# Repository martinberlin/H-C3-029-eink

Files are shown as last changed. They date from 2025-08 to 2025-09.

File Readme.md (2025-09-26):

### nRF52840 mini Badger PCB

This PCB design is based on [this nRF52 module datasheet](https://jlcpcb.com/api/file/downloadByFileSystemAccessId/8612736116701077504)

> E73 - 2 G4 M0 8 S1C are wireless Bluetooth modules designed by
Chengdu Ebyte which feature small size, low power consumption. It
adopt the originally imported RFIC nRF52840 of NORDIC, supporting BLE 4. 2 and BLE 5. 0 . The chip has high- performance ARM CORTEX- M4 F kernel and other peripheral resources, such as
UART, I2C, SPI, ADC, DMA, PWM etc.

The most important goals that this PCB achieves:

 - Very low power consumption. In factors of 2 digits micro-amperes (uA) per minute
 - Simple user interface with a multi-directional switch (up, down, select)
 - All open source, including the BLE sending program (MacOS /iOS)
 - Very simple design and schematics
 - QWIIC connector so can support external I2C sensors (Consumption limit: 200mA, limited by LDO MCP1700-330) 

### PCB 3D Render

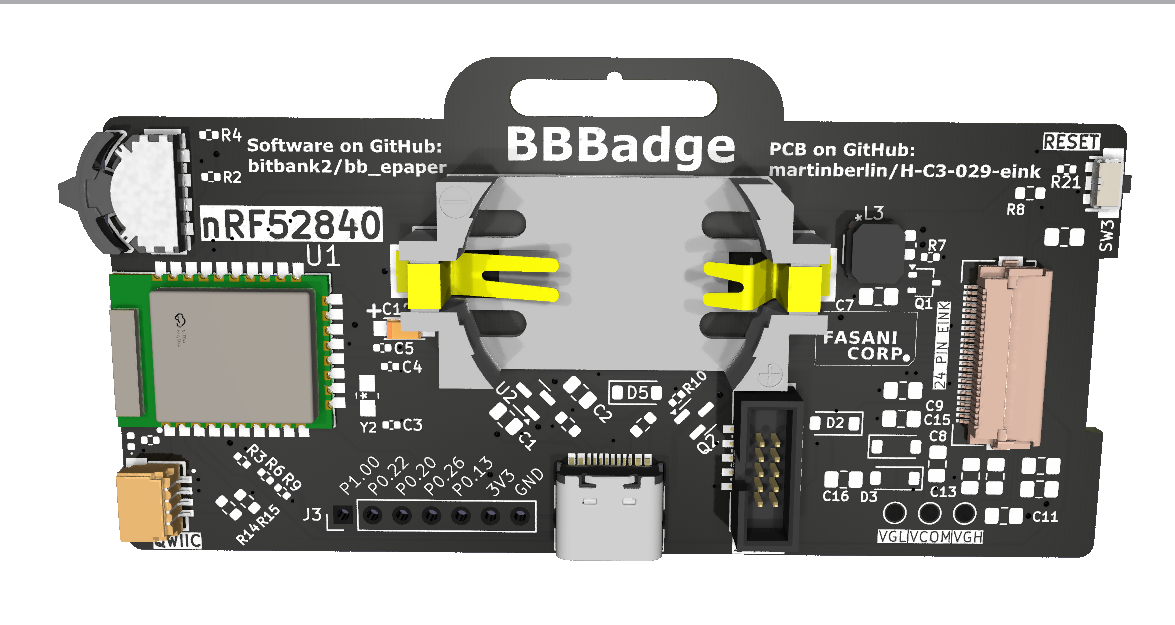
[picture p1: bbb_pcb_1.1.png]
PCB Render


### Related repositories

[MFR Badge](https://github.com/bitbank2/MFRBadge) MacOS/iOS app to program the Maker Faire Rome badges

[bb_epaper](https://github.com/bitbank2/bb_epaper) Larry Bank library for SPI epaper displays

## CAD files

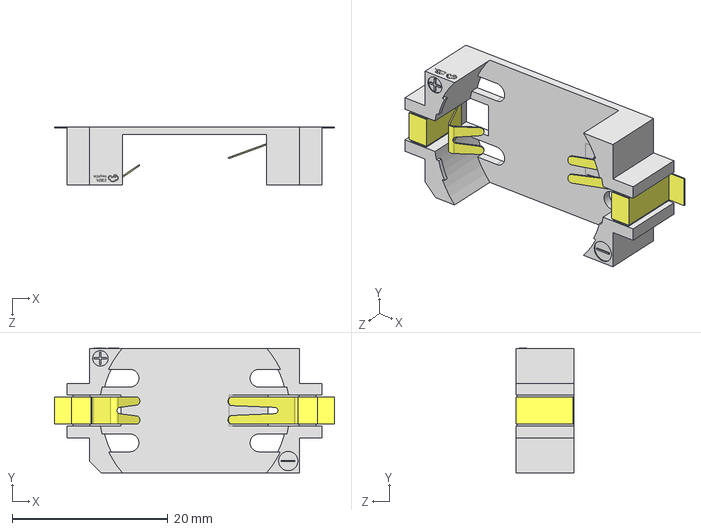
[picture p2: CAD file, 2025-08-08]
H-C3-2.9/components/3D/BAT-SMD_BS-24-B4AA016.step
36.0 x 16.0 x 7.51 mm

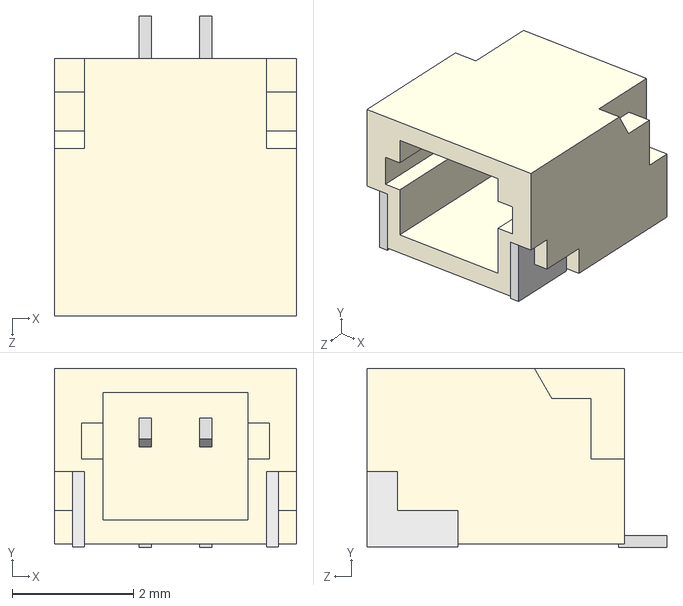
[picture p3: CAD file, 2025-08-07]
H-C3-2.9/components/3D/JST_SM02B-SRSS-TB__LF__SN.stp
4.00 x 2.96 x 4.95 mm

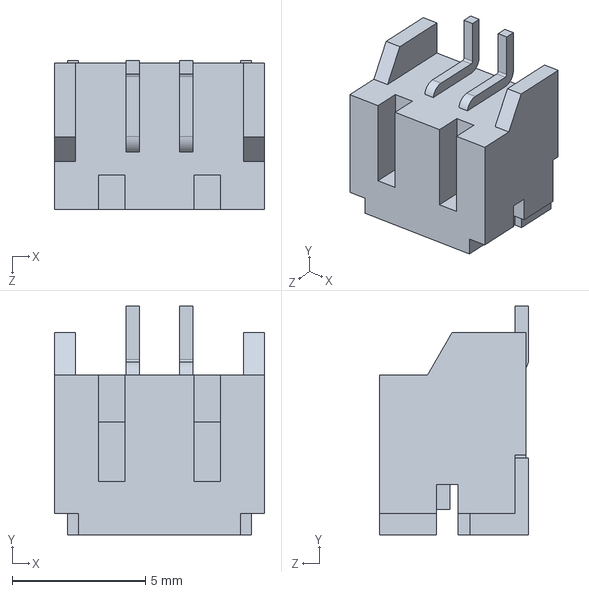
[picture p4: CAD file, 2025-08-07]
H-C3-2.9/components/3D/S2B-PH-SM4-TB_LF__SN_.stp
7.90 x 8.60 x 5.60 mm

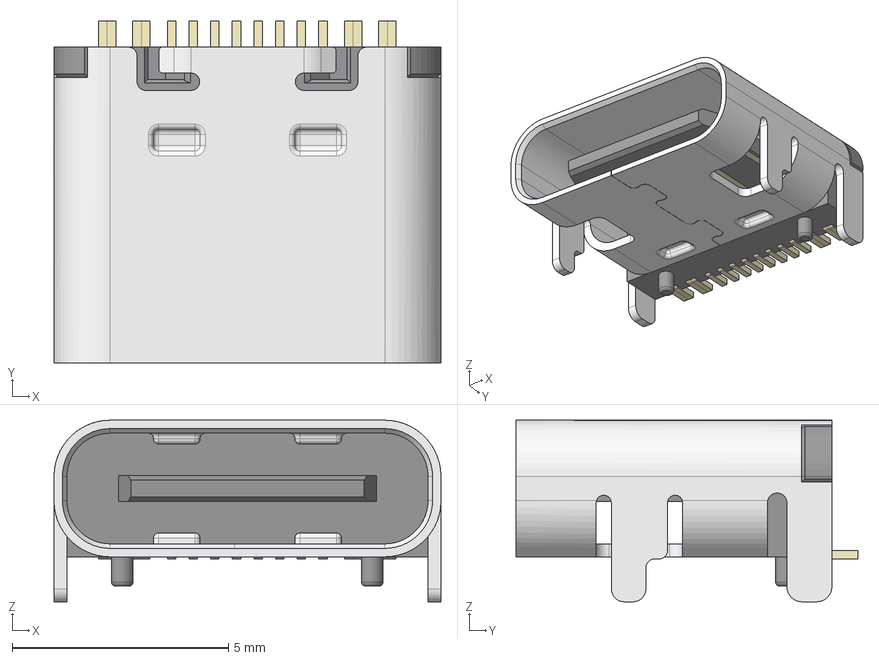
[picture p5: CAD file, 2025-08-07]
H-C3-2.9/components/3D/USB_TYPE-C-31-M-12.step
8.95 x 7.90 x 4.20 mm

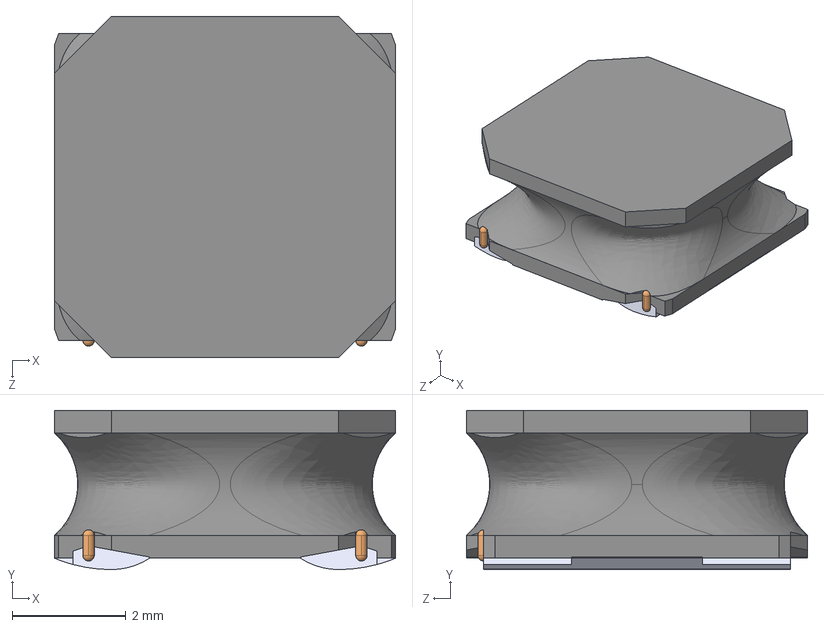
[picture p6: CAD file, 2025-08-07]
H-C3-2.9/components/3D/L-40xx.stp
6.00 x 2.80 x 6.00 mm

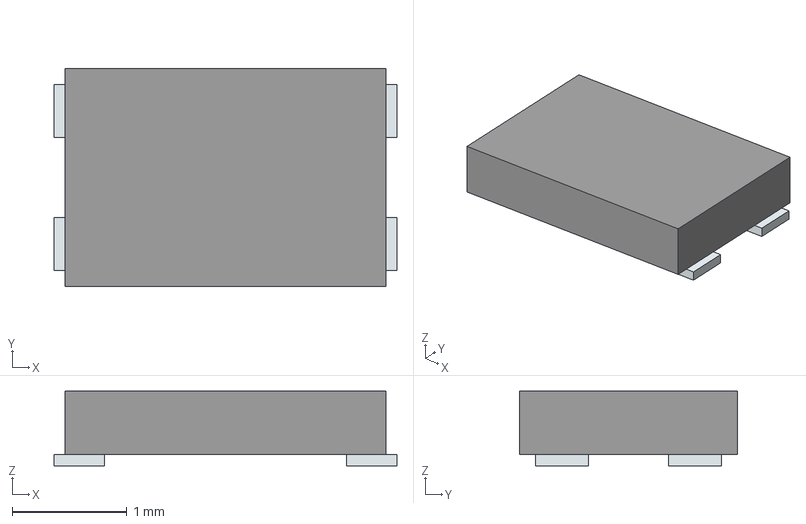
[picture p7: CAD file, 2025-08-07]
H-C3-2.9/components/3D/switch_SKSVCCE010.stp
2.99 x 1.90 x 0.65 mm
Pins

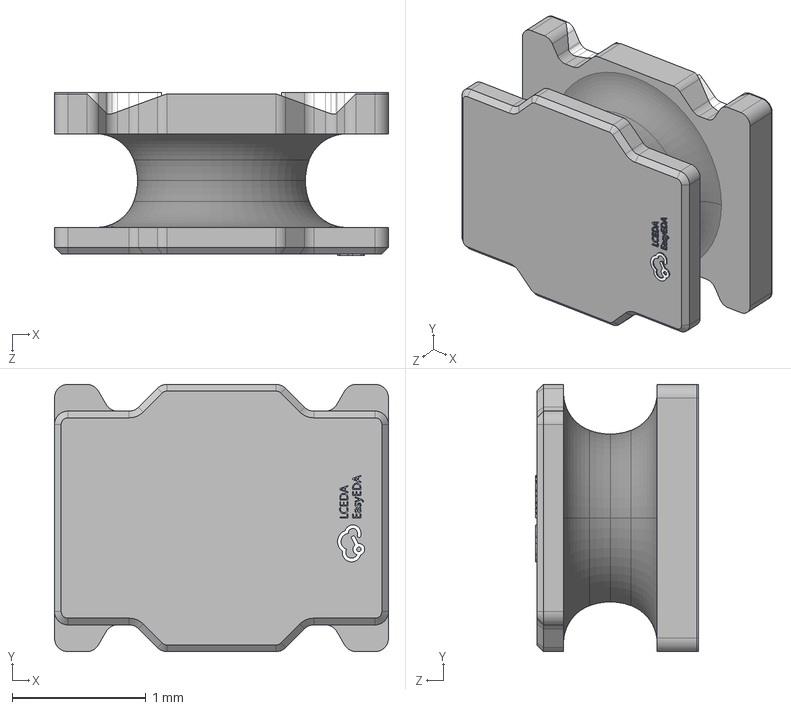
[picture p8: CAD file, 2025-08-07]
H-C3-2.9/components/3D/IND-SMD_L2.5-W2.0-H1.2_SPH252012.step
2.50 x 2.00 x 1.22 mm

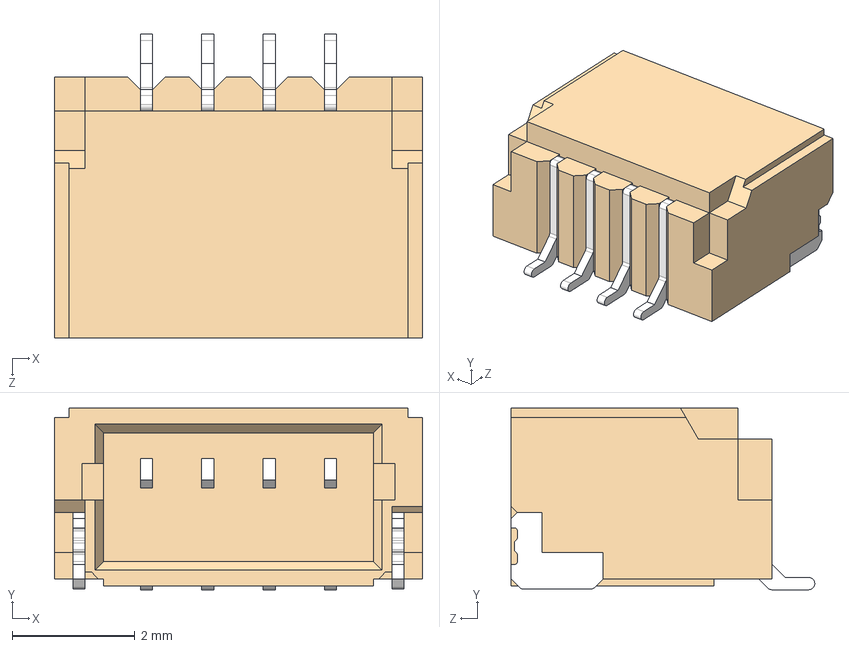
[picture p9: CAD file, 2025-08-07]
H-C3-2.9/components/3D/QWIIC_SM04B-SRSS-TB_LF__SN_.stp
6.00 x 2.96 x 4.95 mm

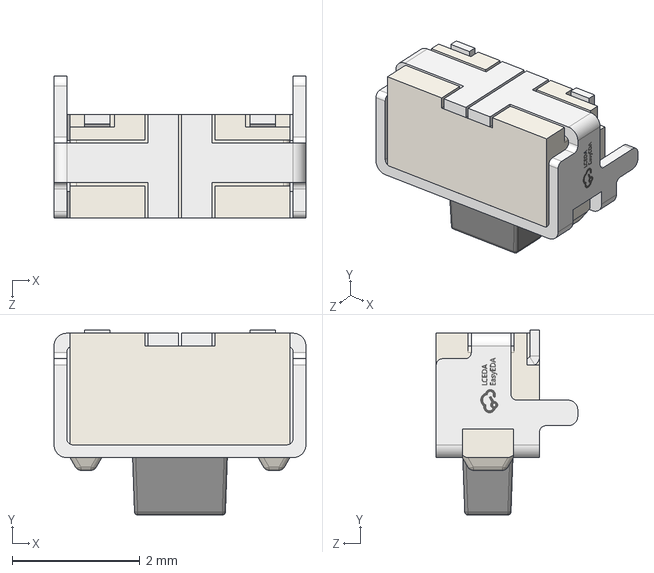
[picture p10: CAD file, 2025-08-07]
H-C3-2.9/components/3D/KEY-SMD_L4.0-W2.9-H1.6-P3.75.step
3.95 x 2.90 x 2.22 mm

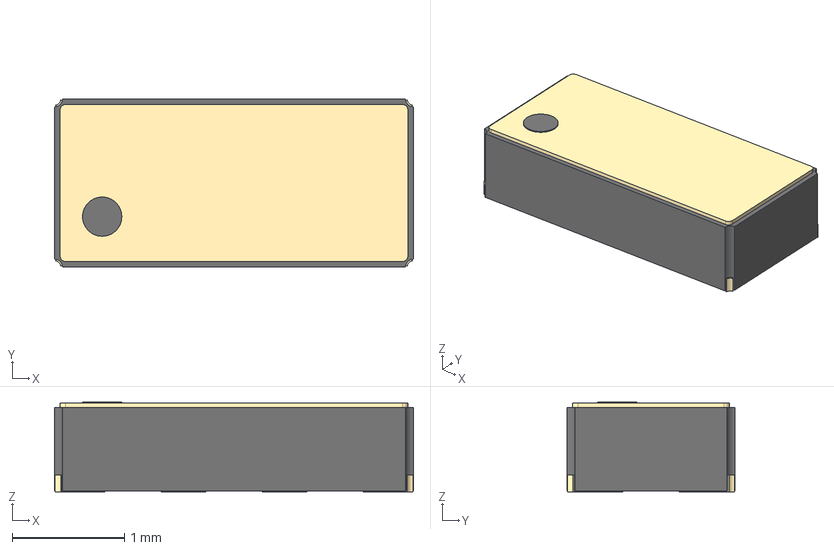
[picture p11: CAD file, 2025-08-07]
H-C3-2.9/components/3D/RV-3032-C7.stp
3.20 x 1.50 x 0.8 mm
Rect2
Rect3
Rect4
Rect5
Terminal

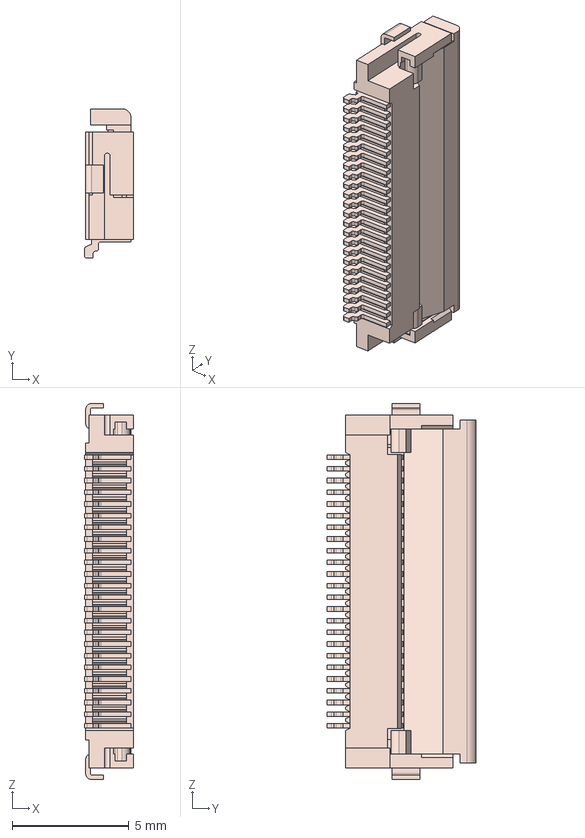
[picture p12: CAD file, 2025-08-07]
H-C3-2.9/components/3D/FH12-24S-0.5SH_55_.step
2.10 x 6.40 x 16.1 mm

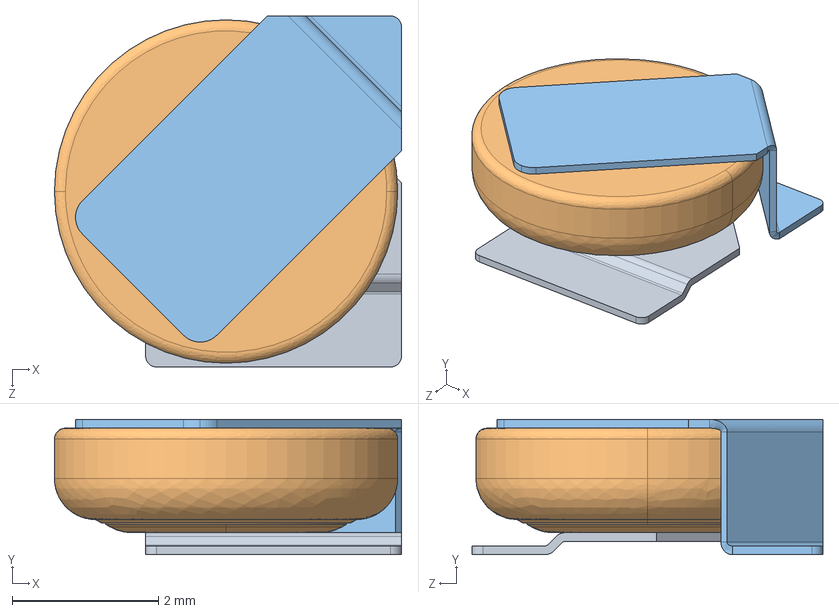
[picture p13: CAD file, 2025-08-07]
H-C3-2.9/components/3D/SuperCAP_XH414HG-IV01E.stp
4.75 x 1.85 x 4.80 mm

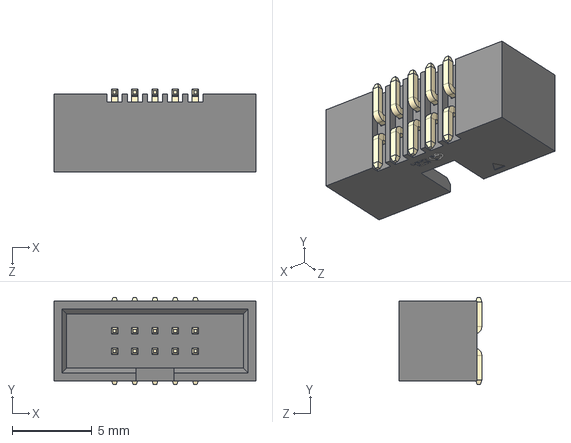
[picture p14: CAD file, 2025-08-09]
H-C3-2.9/components/3D/C42372555-SWD_10P-P1.27.step
12.7 x 5.50 x 5.20 mm

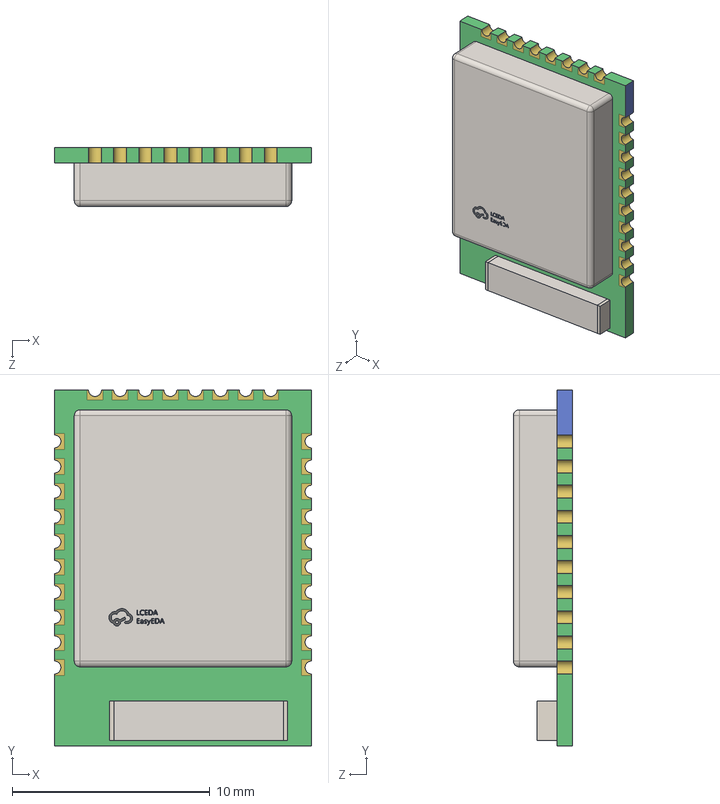
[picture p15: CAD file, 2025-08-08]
H-C3-2.9/components/3D/C356849-nRF52840.step
13.0 x 18.0 x 3.00 mm

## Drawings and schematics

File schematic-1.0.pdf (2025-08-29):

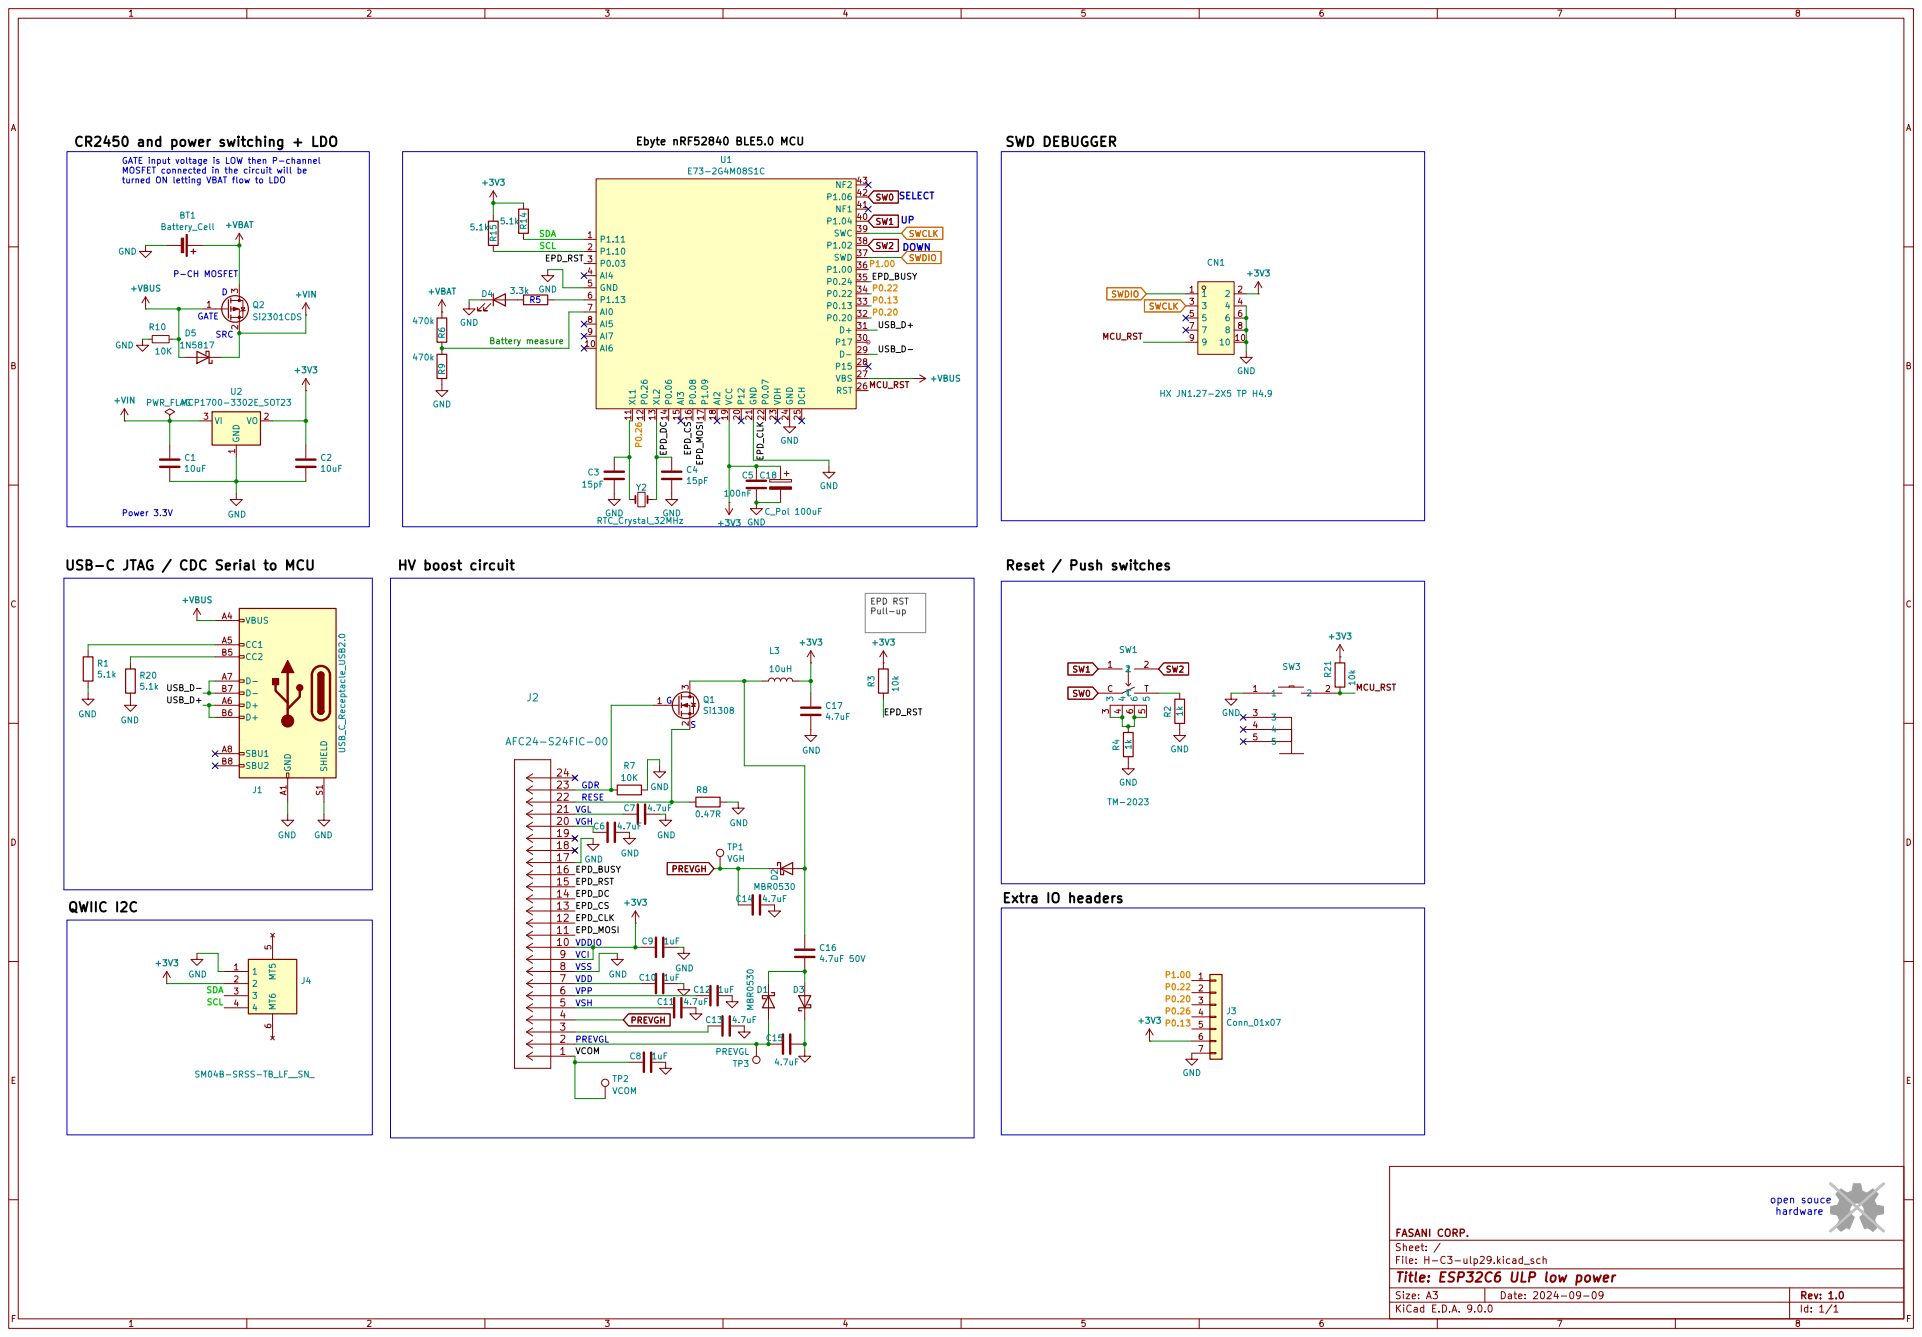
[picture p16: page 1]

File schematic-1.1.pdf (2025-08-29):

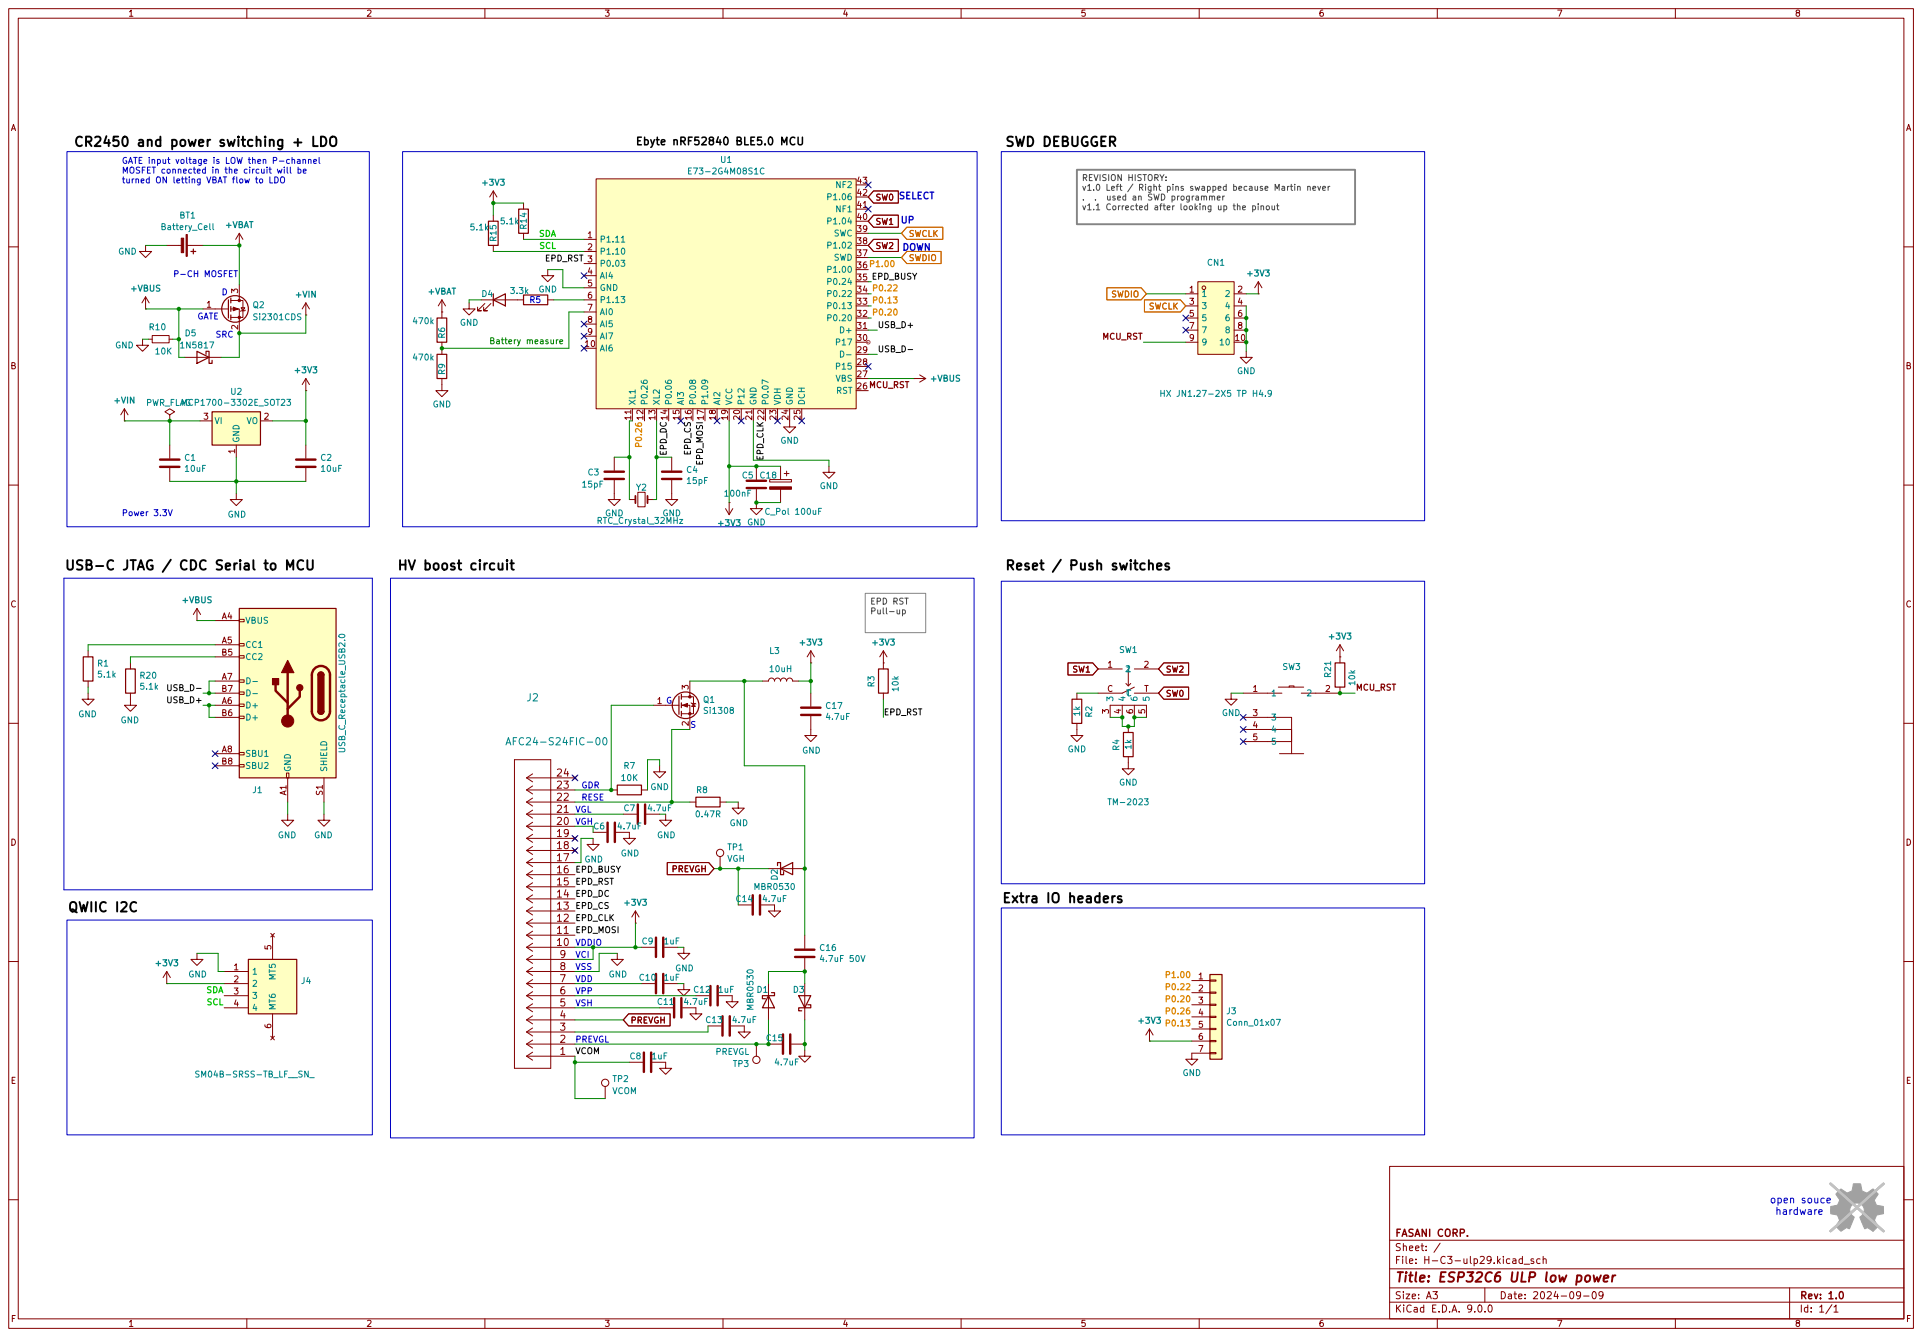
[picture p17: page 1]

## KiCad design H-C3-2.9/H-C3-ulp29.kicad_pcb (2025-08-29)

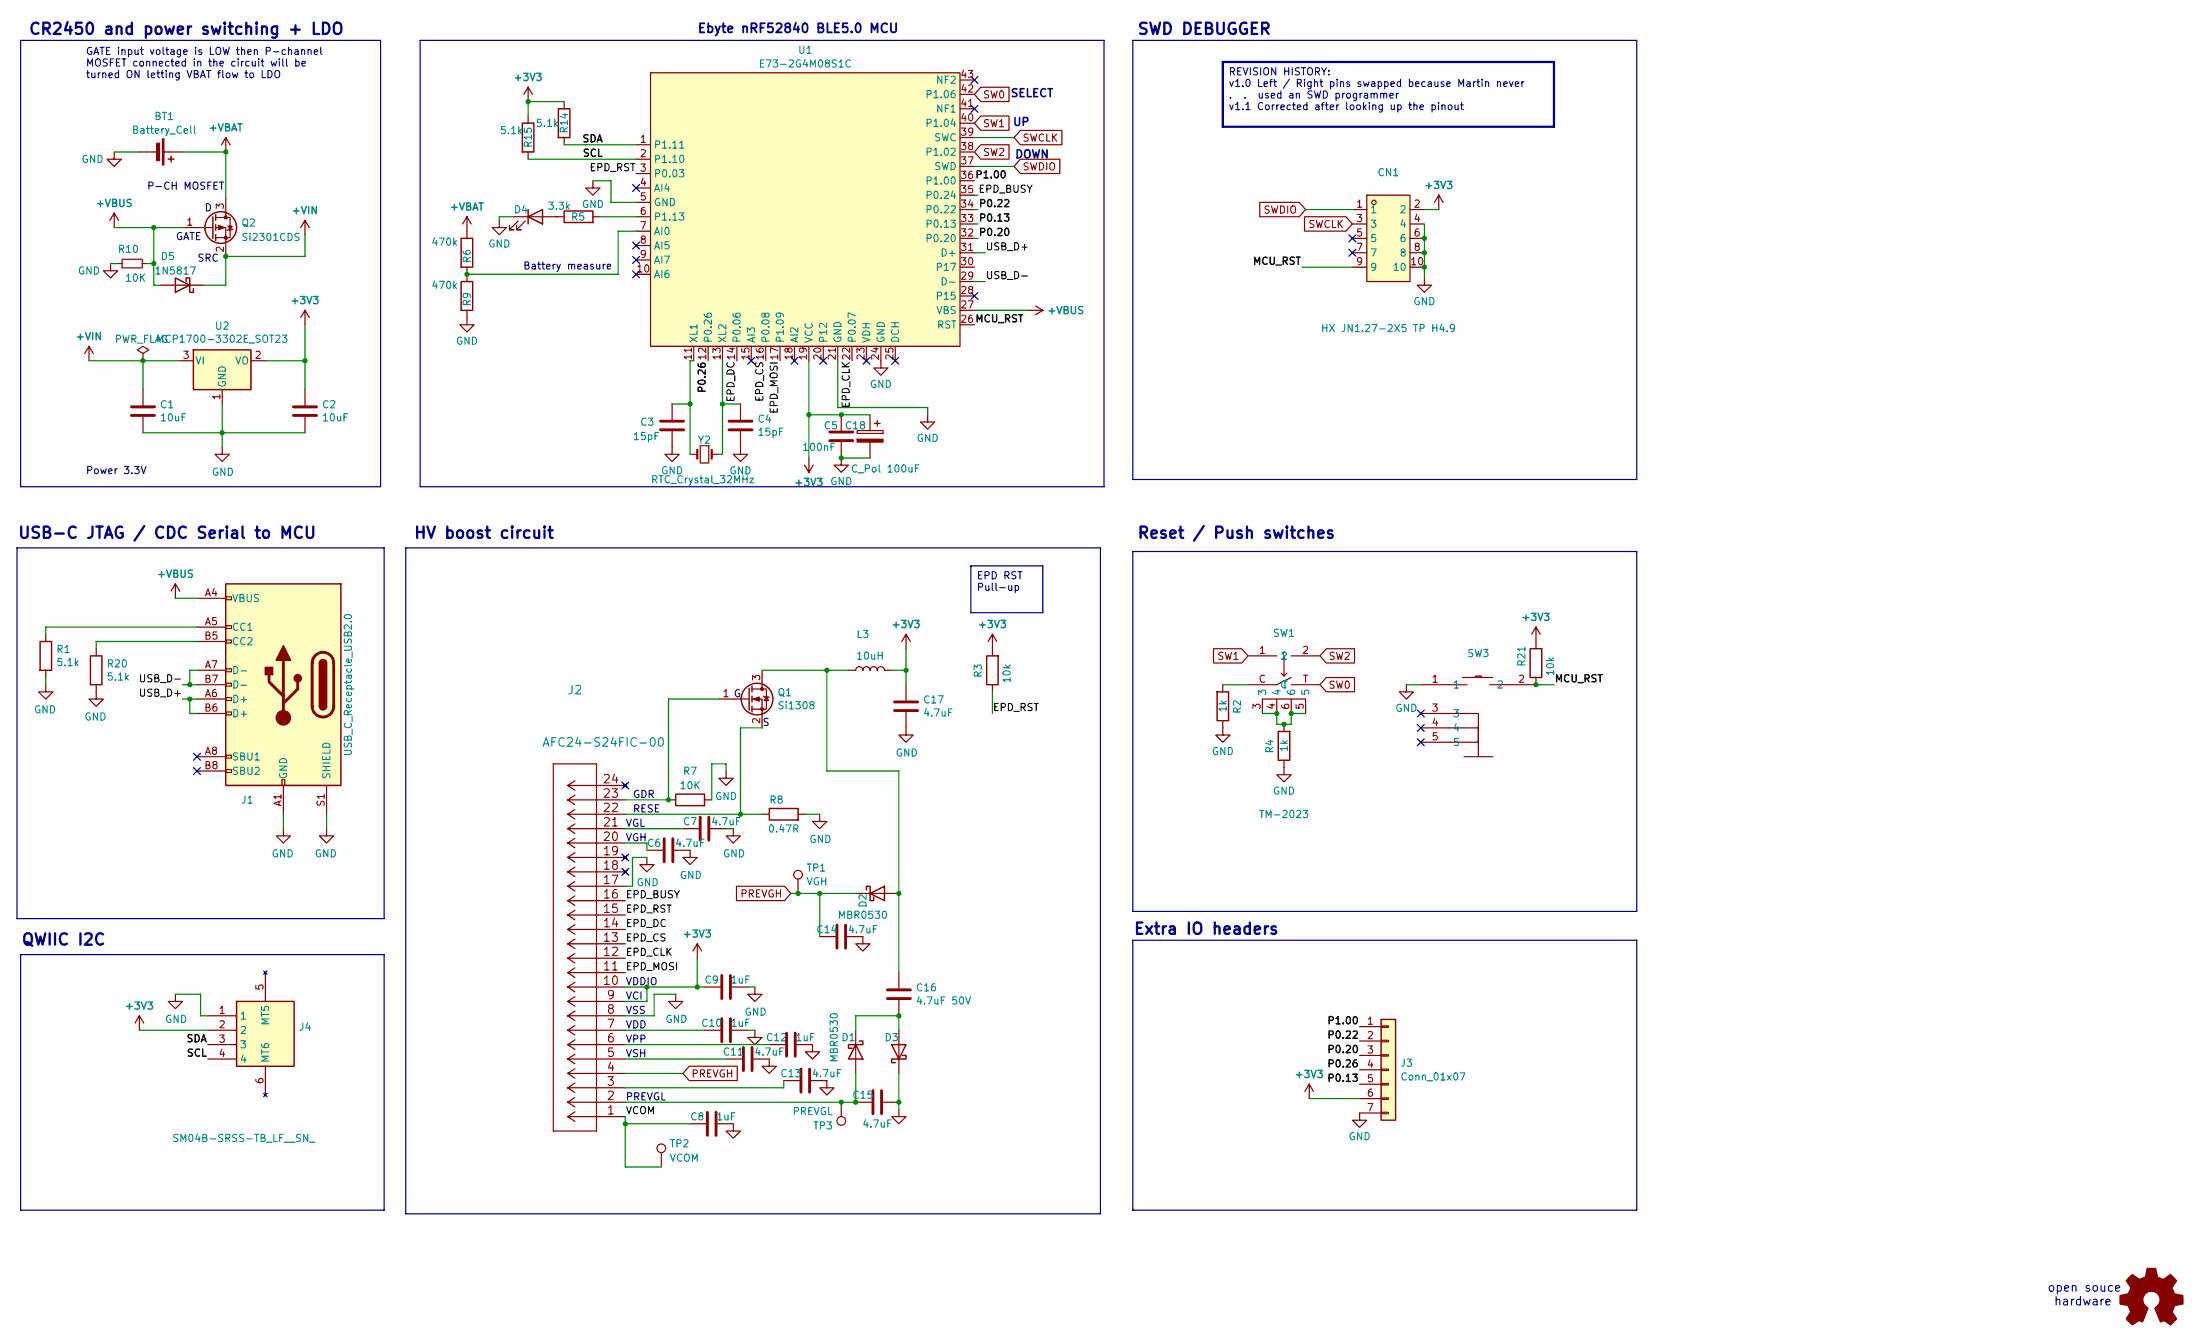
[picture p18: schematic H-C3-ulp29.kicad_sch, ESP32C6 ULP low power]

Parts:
BT1: Battery_Cell; BAT-SMD_BS-24-B4AA016; LCSC C964809
C1, C2: 10uF; C_0805_2012Metric; LCSC C15850
C3, C4: 15pF; C_0402_1005Metric; LCSC C32949
C5: 100nF; C_0402_1005Metric; LCSC C1525
C6, C7, C11, C13, C14, C15: 4.7uF; C_0805_2012Metric_Pad1.18x1.45mm_HandSolder; LCSC C1779
C8, C9, C10, C12: 1uF; C_0805_2012Metric_Pad1.18x1.45mm_HandSolder; LCSC C28323
C16: 4.7uF 50V; C_0805_2012Metric_Pad1.18x1.45mm_HandSolder; LCSC C1779
C17: 4.7uF; C_0603_1608Metric; LCSC C19666
C18: C_Pol 100uF; C7171_CAP; LCSC C7171
CN1: HX JN1.27-2X5 TP H4.9; C42372555-SWD_10P-P1.27; LCSC C42372555
D1, D2, D3: MBR0530; D_SOD-123; LCSC C77336
D4: LED; LED_0402_1005Metric; LCSC C131223
D5: 1N5817; D_SOD-123; LCSC C8598
J1: USB_C_Receptacle_USB2.0; USB_C_Receptacle_HRO_TYPE-C-31-M-12; LCSC C165948
J2: AFC24-S24FIC-00; LCSC C262292
J3: Conn_01x07; PinHeader_1x07_P2.54mm_Vertical
J4: SM04B-SRSS-TB_LF__SN_; QWIIC_SM04B-SRSS-TB_LFSN_; Manufacturer_Part_Number SM04B-SRSS-TB(LF)(SN); LCSC C160404
L3: 10uH; SWPA4030S1R0NT; LCSC C38117
Q1: Si1308; SOT-323_SC-70; LCSC C469327
Q2: Si2301CDS; SOT-23; LCSC C10487
R1, R14, R15, R20: 5.1k; R_0603_1608Metric; LCSC C23186
R2, R4: 1k; R_0402_1005Metric; LCSC C11702
R3, R21: 10k; R_0402_1005Metric; LCSC C25744
R5: 3.3k; R_0402_1005Metric; LCSC C25890
R6, R9: 470k; R_0402_1005Metric; LCSC C22369547
R7, R10: 10K; R_0402_1005Metric; LCSC C25744
R8: 0.47R; R_0603_1608Metric; LCSC C103895
SW1: TM-2023; C318951_TM-2023-1; LCSC C318951
SW3: K2-1806SQ-A2DW-04; KEY-SMD_K2-1806SQ-A3DW-04; LCSC C19100323
TP1: VGH; TestPoint_Pad_D1.5mm
TP2: VCOM; TestPoint_Pad_D1.5mm
TP3: PREVGL; TestPoint_Pad_D1.5mm
U1: E73-2G4M08S1C; C356849-nRF52840; LCSC C356849
U2: MCP1700-3302E_SOT23; SOT-23; LCSC C39051
Y2: RTC_Crystal_32MHz; Q13FC1350000400-Crystal; LCSC C32346

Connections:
+3V3: C2.2, C5.2, C9.2, C17.2, C18.1, CN1.2, J2.9, J2.10, J3.6, J4.2, L3.2, R3.2, R14.1, R15.1, R21.2, U1.19 (VCC), U2.2 (VO)
+VBAT: BT1.1 (+), Q2.3 (D), R6.1
+VBUS: D5.2 (A), J1.A4 (VBUS), J1.A9 (VBUS), J1.B4 (VBUS), J1.B9 (VBUS), Q2.1 (G), R10.2, U1.27 (VBS)
+VIN: C1.2, D5.1 (K), Q2.2 (S), U2.3 (VI)
/EPD_BUSY: J2.16, U1.35 (P0.24)
/EPD_CLK: J2.12, U1.22 (P0.07)
/EPD_CS: J2.13, U1.16 (P0.08)
/EPD_DC: J2.14, U1.14 (P0.06)
/EPD_MOSI: J2.11, U1.17 (P1.09)
/EPD_RST: J2.15, R3.1, U1.3 (P0.03)
/MCU_RST: CN1.9, R21.1, SW3.2, U1.26 (RST)
/P0.13: J3.5, U1.33 (P0.13)
/P0.20: J3.3, U1.32 (P0.20)
/P0.22: J3.2, U1.34 (P0.22)
/P0.26: J3.4, U1.12 (P0.26)
/P1.00: J3.1, U1.36 (P1.00)
/SCL: J4.4, R15.2, U1.2 (P1.10)
/SDA: J4.3, R14.2, U1.1 (P1.11)
/USB_D+: J1.A6 (D+), J1.B6 (D+), U1.31 (D+)
/USB_D-: J1.A7 (D-), J1.B7 (D-), U1.29 (D-)
/VCOM: C8.2, J2.1, TP2.1
GND: BT1.2 (-), C1.1, C2.1, C3.1, C4.1, C5.1, C6.1, C7.1, C8.1, C9.1, C10.1, C11.1, C12.1, C13.1, C14.1, C15.1, C17.1, C18.2, CN1.4, CN1.6, CN1.8, CN1.10, D3.1 (K), D4.1 (K), J1.A1 (GND), J1.A12 (GND), J1.B1 (GND), J1.B12 (GND), J1.S1 (SHIELD), J2.8, J2.17, J3.7, J4.1, R1.2, R2.1, R4.1, R7.2, R8.2, R9.2, R10.1, R20.2, SW3.1, U1.5 (GND), U1.21 (GND), U1.24 (GND), U2.1 (GND)
unnamed: C6.2, J2.20
unnamed: C7.2, J2.21
unnamed: C10.2, J2.7
unnamed: C11.2, J2.5
unnamed: C12.2, J2.6
unnamed: C13.2, J2.3
unnamed: C15.2, D1.2 (A), J2.2, TP3.1
unnamed: C16.1, D1.1 (K), D3.2 (A)
unnamed: C16.2, D2.2 (A), L3.1, Q1.3 (D)
unnamed: D4.2 (A), R5.1
unnamed: J1.A5 (CC1), R1.1
unnamed: J1.B5 (CC2), R20.1
unnamed: J2.23, Q1.1 (G), R7.1
unnamed: J2.22, Q1.2 (S), R8.1
unnamed: R2.2, SW1.C
unnamed: R4.2, SW1.3, SW1.4, SW1.5, SW1.6
unnamed: R6.2, R9.1, U1.7 (AI0)
unnamed: R5.2, U1.6 (P1.13)
unnamed: C3.2, U1.11 (XL1), Y2.2
unnamed: C4.2, U1.13 (XL2), Y2.1
PREVGH: C14.2, D2.1 (K), J2.4, TP1.1
SW0: SW1.T, U1.42 (P1.06)
SW1: SW1.1, U1.40 (P1.04)
SW2: SW1.2, U1.38 (P1.02)
SWCLK: CN1.3, U1.39 (SWC)
SWDIO: CN1.1, U1.37 (SWD)

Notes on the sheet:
USB-C JTAG / CDC Serial to MCU
Power 3.3V
Ebyte nRF52840 BLE5.0 MCU
VGH
RESE
VGL
HV boost circuit
VSH
VPP
QWIIC I2C
SRC
GATE
Extra IO headers
open souce hardware
GDR
SELECT
P-CH MOSFET
Battery measure
DOWN
Reset / Push switches
VDDIO
GATE input voltage is LOW then P-channel MOSFET connected in the circuit will be turned ON letting VBAT flow to LDO
SWD DEBUGGER
PREVGL
VSS
VCI
CR2450 and power switching + LDO
VDD
REVISION HISTORY: v1.0 Left / Right pins swapped because Martin never . . used an SWD programmer v1.1 Corrected after looking up the pinout
EPD RST Pull-up

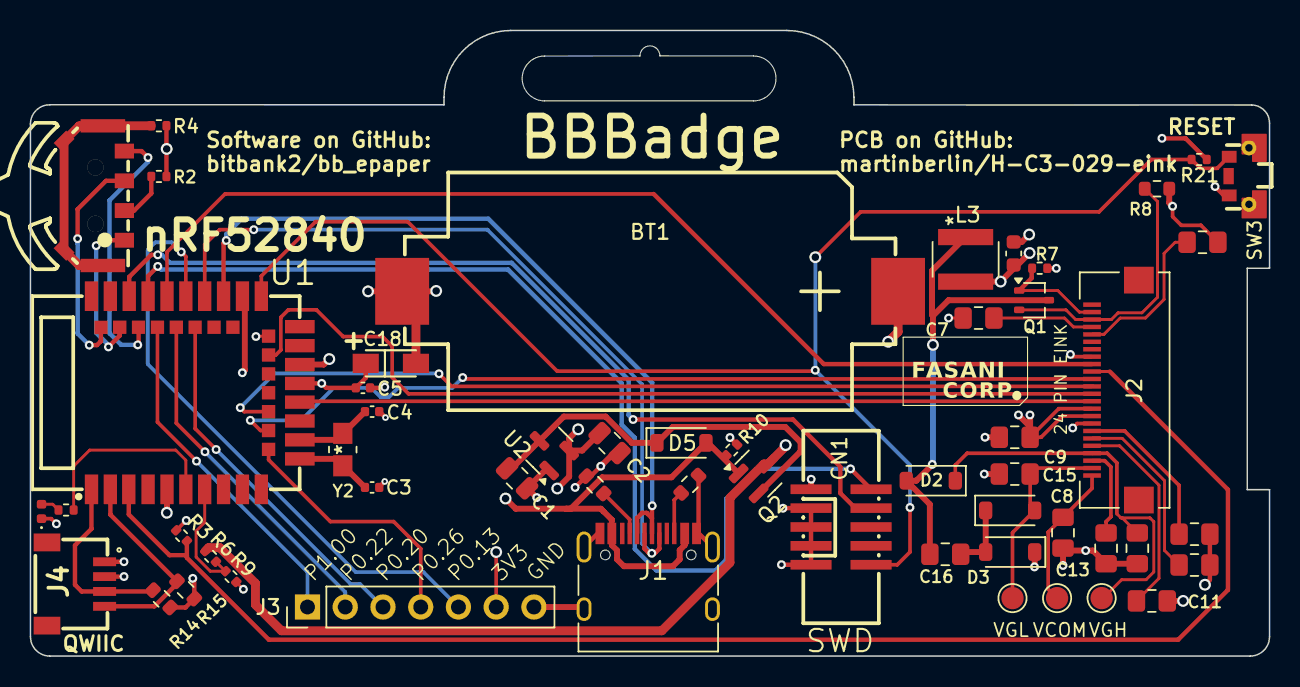
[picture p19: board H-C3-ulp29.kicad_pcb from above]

Board: 4 copper layers, 83.4 x 42.1 mm, 54 parts (0 on the bottom side), 48 nets.

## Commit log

2025-08-07 Initial commit, unfinished board
    [2450AT42E0100E-ANT.stp, BOM.xlsx, Crytal_ECS-40Mhz_ECS.step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]
2025-08-07 Add PCF RTC
    [BOM.xlsx, H-C3-ulp29.kicad_sch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]
2025-08-08 Layout 1.0
    [H-C3-ulp29.kicad_pcb, H-C3-ulp29.kicad_sch]
2025-08-08 Schematics updated. All parts on board
    [BAT-SMD_BS-24-B4AA016.step, H-C3-ulp29.kicad_pcb, H-C3-ulp29.kicad_sch]
2025-08-08 Going forward
    [2450AT42E0100E-ANT.stp, C518912-nRF52_SMD.step, Crytal_ECS-40Mhz_ECS.step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]
2025-08-08 Final decision about MCU
    [C356849-nRF52840.step, C518912-nRF52_SMD.step, H-C3-ulp29.kicad_pcb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]
2025-08-09 Starting to test routing posibilities
    [H-C3-ulp29.kicad_pcb, H-C3-ulp29.kicad_sch]
2025-08-09 Please approve routing
    [C42372555-SWD_10P-P1.27.step, H-C3-ulp29.kicad_pcb, H-C3-ulp29.kicad_sch]
2025-08-09 Add nRF52 RTC crystal
    [H-C3-ulp29.kicad_pcb, H-C3-ulp29.kicad_sch]
2025-08-09 Placing new knob
    [H-C3-ulp29.kicad_pcb, H-C3-ulp29.kicad_sch]
2025-08-09 RTC is out, use internal one
    [H-C3-ulp29.kicad_pcb, H-C3-ulp29.kicad_sch]
2025-08-09 1.0 schematics needs last feedback
    [H-C3-ulp29.kicad_sch]
2025-08-09 Pre-release please check routing
    [H-C3-ulp29.kicad_pcb, H-C3-ulp29.kicad_sch]
2025-08-10 FAB attempt 1
    [H-C3-ulp29-B_Cu.gbr, H-C3-ulp29-B_Mask.gbr, H-C3-ulp29-B_Paste.gbr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]
2025-08-10 Modified front silkscreen info
    [H-C3-ulp29.kicad_pcb]
2025-08-29 Updated for 1.1
    [H-C3-ulp29-B_Cu.gbr, H-C3-ulp29-B_Mask.gbr, H-C3-ulp29-B_Paste.gbr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]
2025-08-29 Last corrections after KiCad updated (was done already for 1.0)
    [H-C3-ulp29.kicad_pcb]
2025-09-26 Add PCB Preview

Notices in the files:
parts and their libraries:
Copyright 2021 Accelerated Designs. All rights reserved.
